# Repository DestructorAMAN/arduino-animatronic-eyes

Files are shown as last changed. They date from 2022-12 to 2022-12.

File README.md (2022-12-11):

# Arduino Animatronic Eyes
A computer science project I've build with a friend of mine. It's a pair of eyes which follow you when you walk past it.

The original code is (mostly) copied from [github.com/Nimrod-Galor/eye-animatronics](https://github.com/Nimrod-Galor/eye-animatronics)

We decided to put the eyes in a box behind a picture of Mark Zuckerberg. This way it looks like he's always watching you (as his eyes will follow you when you walk past him).

Front image
Back image
<details>
	<summary>Click to view the demo!</summary>
	Demo Video
</details>

# Material list
* The 3d printed files (see below)
* The laser cut files (see below) (if you only want the eyes and not the box, you can skip this)
* Arduino UNO
* 5x 9g servo
* ADNS 3080
* Jumper cables
* Optionally: IR LED's (+ matching resistors) for better visibility

# Tools list
* 3D printer => for the frame, eyeballs, eyelids and u-joints
* Laser cutter => for the box
* Soldering iron => to solder the jumper cables together

# 3D printed files
We've combined two thingiverse projects, [Doorman with eye holder & eyeball improvements](https://www.thingiverse.com/thing:3190675) and [The Doorman - Eyeball with ball joint](https://www.thingiverse.com/thing:3182820). The frame, eyeball and u-joint are from the first project. The eyelid is from the second one.

The eyes in the first design have a better connection with the frame (u-joint vs ball-joint). However, that design doesn't include the eyelid. The eyelid from the second design is compatible with the first design, so we just took it from there.

All files we used can be found in the `3d-files` directory. Remember that you need 2 eyeballs, 2 eyelids (you should scale them up a bit yourself) and 2 u-joints if you want to build this yourself.

# Laser cut files
We've laser cut the `box.svg` and `front_box.svg` from the `laser-files` directory. The dimensions of the box are the following: height: 47cm, width: 36cm.

The foam board we orded online with the dimensions of 34cm x 43cm and the file `zuck.webp` printed on it.

We hot glued the foam board to the back of the front panel, and hot glued the front panel to the sides. To mount the eyes we placed a small plate inside the box and glued everything together.

# Schematics
Schematics

# Capturing frames from the camera
You can use [github.com/RCmags/ADNS3080_frame_capture](https://github.com/RCmags/ADNS3080_frame_capture) to capture frames from the ADNS 3080. It requires you to first flash the `arduino_serial_output.ino` to the arduino and then run the python script. Make sure to set the correct serial port in the python script.

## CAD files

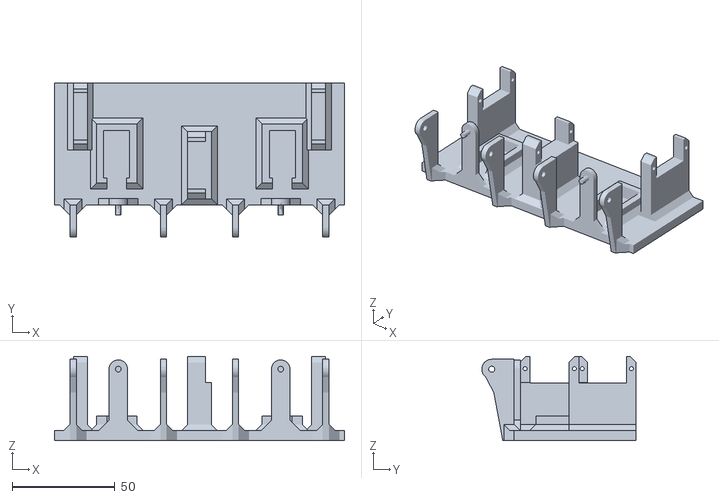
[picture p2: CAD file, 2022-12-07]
3d-files/frame.stl
140.9 x 75.0 x 41.0

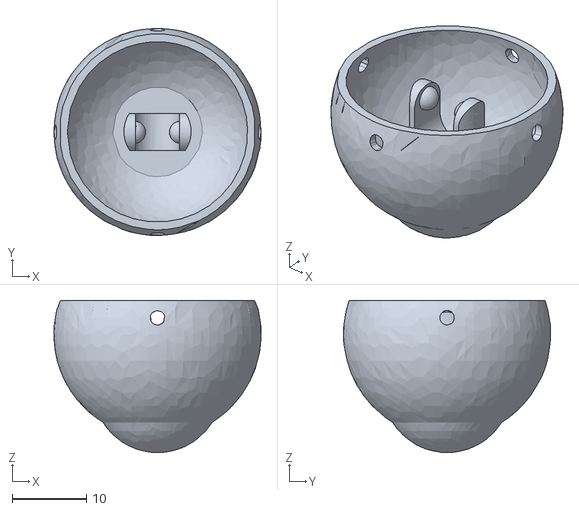
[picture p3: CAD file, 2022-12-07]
3d-files/eyeball.stl
27.9 x 28.0 x 20.6

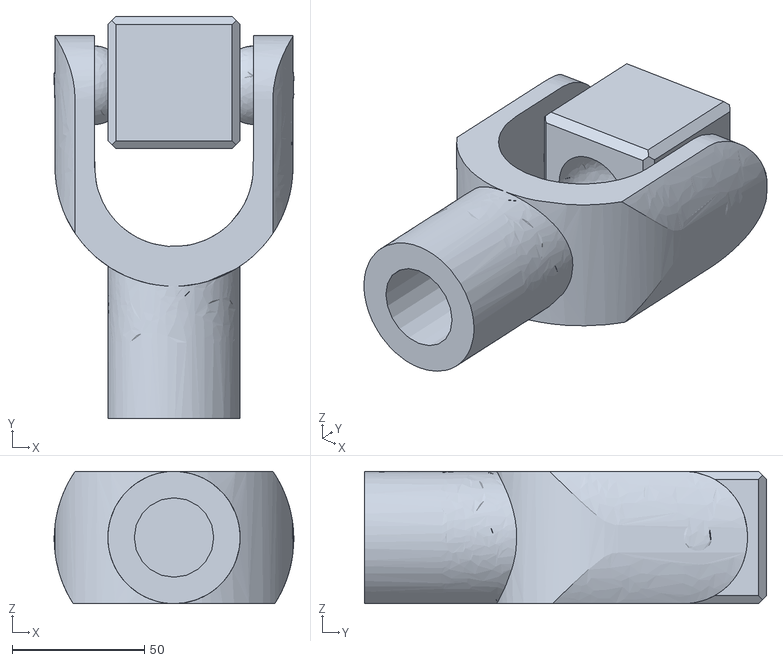
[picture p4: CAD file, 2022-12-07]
3d-files/ujoint.stl
90.6 x 152.0 x 50.0

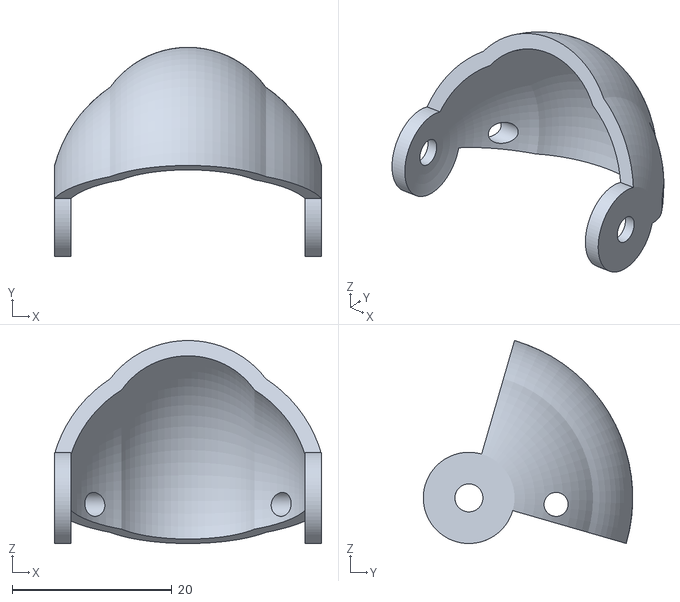
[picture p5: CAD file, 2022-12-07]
3d-files/eyelid.stl
33.4 x 26.2 x 25.4

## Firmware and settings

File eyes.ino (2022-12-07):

// import required libraries
#include <SPI.h>
#include <Servo.h>

// Debugging
#define DEBUG_QUALITY 0 // Print the quality of the camera if set to 1
#define DEBUG_XY 0 // Print the x/y coordinates if set to 1

// Left/right eye seen as the zuck himself (left eye in code = right eye if you stand in front of it)
Servo srvRx; // pin 2 - right eye swing
Servo srvRy; // pin 3 - right eye tilt
Servo srvLx; // pin 7 - left eye swing
Servo srvLy; // pin 6 - left eye tilt
Servo srvShut; // pin 5 - eyelids open/close

// Starting positions of the servo's
int posX = 90; // swing middle position
int posY = 90; // tilt middle position
int posS = 90; // shut start position

// Boundaries
// Without boundaries the servo's could move too far and break the eyes
// Or move too far and break the metal wire
short blinkMax = 105; // boundaries for eyelids
short blinkMin = 165; // boundaries for eyelids
short yMin = 39; // eye max up position
short yMax = 153; // eye max down position
short xMin = 60; // eye max right position
short xMax = 127; // eye max left position
short posYrev = 90; // reversed eye tilt position

// Other variables
short loopDelay = 10; // Slow down the loop with 10 ms

// Loop time for blinking
unsigned long blinkTime = 2000;

// No movement detected => rest = true => eyelids closed
unsigned long lastTrack = 0; // keeps track of when the last time movement is detected
bool rest = true; // keeps track of whether the eyes are in rest position (eyelids closed) or not

// Camera pins
#define PIN_MISO 12
#define PIN_MOSI 11
#define PIN_SCK 13
#define PIN_MOUSECAM_RESET 9
#define PIN_MOUSECAM_CS 10

// Amount of pixels on the camera
#define ADNS3080_PIXELS_X 30
#define ADNS3080_PIXELS_Y 30

// Camera Configuration
#define ADNS3080_PRODUCT_ID            0x00
#define ADNS3080_REVISION_ID           0x01
#define ADNS3080_MOTION                0x02
#define ADNS3080_DELTA_X               0x03
#define ADNS3080_DELTA_Y               0x04
#define ADNS3080_SQUAL                 0x05
#define ADNS3080_PIXEL_SUM             0x06
#define ADNS3080_MAXIMUM_PIXEL         0x07
#define ADNS3080_CONFIGURATION_BITS    0x0a
#define ADNS3080_EXTENDED_CONFIG       0x0b
#define ADNS3080_DATA_OUT_LOWER        0x0c
#define ADNS3080_DATA_OUT_UPPER        0x0d
#define ADNS3080_SHUTTER_LOWER         0x0e
#define ADNS3080_SHUTTER_UPPER         0x0f
#define ADNS3080_FRAME_PERIOD_LOWER    0x10
#define ADNS3080_FRAME_PERIOD_UPPER    0x11
#define ADNS3080_MOTION_CLEAR          0x12
#define ADNS3080_FRAME_CAPTURE         0x13
#define ADNS3080_SROM_ENABLE           0x14
#define ADNS3080_FRAME_PERIOD_MAX_BOUND_LOWER      0x19
#define ADNS3080_FRAME_PERIOD_MAX_BOUND_UPPER      0x1a
#define ADNS3080_FRAME_PERIOD_MIN_BOUND_LOWER      0x1b
#define ADNS3080_FRAME_PERIOD_MIN_BOUND_UPPER      0x1c
#define ADNS3080_SHUTTER_MAX_BOUND_LOWER           0x1e
#define ADNS3080_SHUTTER_MAX_BOUND_UPPER           0x1e
#define ADNS3080_SROM_ID               0x1f
#define ADNS3080_OBSERVATION           0x3d
#define ADNS3080_INVERSE_PRODUCT_ID    0x3f
#define ADNS3080_PIXEL_BURST           0x40
#define ADNS3080_MOTION_BURST          0x50
#define ADNS3080_SROM_LOAD             0x60
#define ADNS3080_PRODUCT_ID_VAL        23

// Reset the camera
void mousecam_reset()
{
  digitalWrite(PIN_MOUSECAM_RESET, HIGH);
  delay(1); // reset pulse >10us
  digitalWrite(PIN_MOUSECAM_RESET, LOW);
  delay(35); // 35ms from reset to functional
}

// Initialize/setup the camera
int mousecam_init()
{
  pinMode(PIN_MOUSECAM_RESET, OUTPUT);
  pinMode(PIN_MOUSECAM_CS, OUTPUT);
  digitalWrite(PIN_MOUSECAM_CS, HIGH);

  // Reset the camera
  mousecam_reset();

  // Make sure the camera is correctly connected by fetching the PID
  digitalWrite(PIN_MOUSECAM_CS, LOW);
  SPI.transfer(ADNS3080_PRODUCT_ID);
  delayMicroseconds(75);
  int pid = SPI.transfer(0xff);
  digitalWrite(PIN_MOUSECAM_CS, HIGH);
  delayMicroseconds(1);

  // Make sure the product id matches
  if (pid != ADNS3080_PRODUCT_ID_VAL) {
    Serial.println("PID Changed:");
    Serial.println(pid);
    return -1;
  }

  // Turn on sensitive mode
  digitalWrite(PIN_MOUSECAM_CS, LOW);
  SPI.transfer(ADNS3080_CONFIGURATION_BITS | 0x80);
  SPI.transfer(0x19);
  digitalWrite(PIN_MOUSECAM_CS, HIGH);
  delayMicroseconds(50);

  return 0;
}

// Related to fetching data from the camera
struct MD
{
  byte motion;
  char dx, dy;
  byte squal;
  word shutter;
  byte max_pix;
};

void mousecam_read_motion(struct MD *p)
{
  digitalWrite(PIN_MOUSECAM_CS, LOW);
  SPI.transfer(ADNS3080_MOTION_BURST);
  delayMicroseconds(75);
  p->motion = SPI.transfer(0xff);
  p->dx = SPI.transfer(0xff);
  p->dy = SPI.transfer(0xff);
  p->squal = SPI.transfer(0xff);
  p->shutter = SPI.transfer(0xff) << 8;
  p->shutter |= SPI.transfer(0xff);
  p->max_pix = SPI.transfer(0xff);
  digitalWrite(PIN_MOUSECAM_CS, HIGH);
  delayMicroseconds(5);
}

void setup()
{
  // Start serial connection on 57600
  Serial.begin(57600);

  // Set camera pins as input/output
  pinMode(PIN_MISO, INPUT);
  pinMode(PIN_MOSI, OUTPUT);
  pinMode(PIN_SCK, OUTPUT);

  // Configure serial connection with camera
  SPI.begin();
  SPI.setClockDivider(SPI_CLOCK_DIV32);
  SPI.setDataMode(SPI_MODE3);
  SPI.setBitOrder(MSBFIRST);

  // Make sure the camera is setup correctly
  if (mousecam_init() == -1)
  {
    Serial.println("Mouse cam failed to init");
    while (1);
  }

  // Set pins for servo's
  srvRx.attach(2);
  srvRy.attach(3);
  srvLx.attach(7);
  srvLy.attach(6);
  srvShut.attach(5);

  // Set servo's to start position
  srvRx.write(posX);
  srvLx.write(posX);
  srvRy.write(posY);
  srvLy.write(posY);
  srvShut.write(blinkMax);
}

void loop()
{
  // Slow down the loop
  delay(loopDelay);

  // Blinking mechanism
  if (!rest) {
    blinkTime = blinkTime - loopDelay;

    // When "blinkTime" is between 500 and 100 the eyelids will close and open
    if (blinkTime <= 100) { // Open eyelids
      srvShut.write(blinkMin);
      blinkTime = random(2, 12) * 500;
    } else if (blinkTime <= 500) { // Close eyelids
      srvShut.write(blinkMax);
    }
  }

  // Fetch the movement from the camera
  MD md;
  mousecam_read_motion(&md);

  // Quality debugging
  if (DEBUG_QUALITY != 0) {
    Serial.println(md.squal);
  }

  // If movement in x direction is detected
  if ((int)md.dx != 0) {

    // Make sure eyes are open when movement is detected (not in rest)
    if (rest) {
      srvShut.write(blinkMin);
      rest = false;
    }

    // Calculate new servo position
    posX -= (int)md.dx;
    if (posX > xMax) {
      posX = xMax;
    } else if (posX < xMin) {
      posX = xMin;
    }

    // Set eyes to new x position (swing)
    srvRx.write(180 - posX);
    srvLx.write(180 - posX);

    // Print x coordinate
    if (DEBUG_XY != 0) {
      Serial.print("X: ");
      Serial.println(posX);
    }

    // Update when last movement is detected
    lastTrack = millis();
  }

  // If movement in y direction is detected
  if ((int)md.dy != 0) {

    // Make sure eyes are open when movement is detected (not in rest)
    if (rest) {
      srvShut.write(blinkMin);
      rest = false;
    }

    // Calculate new servo position
    posY -= (int)md.dy;
    if (posY > yMax) {
      posY = yMax;
    } else if (posY < yMin) {
      posY = yMin;
    }

    // Set eyes to new y position (tilt)
    // Calculate reversed position (the left servo is rotated 180 degrees)
    posYrev = map(posY, yMin, yMax, yMax, yMin);
    srvRy.write(posY);
    srvLy.write(posYrev);

    // Print y coordinate
    if (DEBUG_XY != 0) {
      Serial.print("Y: ");
      Serial.println(posY);
    }

    // Update when last movement is detected
    lastTrack = millis();
  }

  // When no movement detected for 3 seconds, go to "rest" position (eyelids closed)
  if (millis() - lastTrack >= 3000) {
    rest = true;
    posX = 90; // swing
    posY = 90; // tilt
    posS = 90; // shut

    srvRx.write(posX);
    srvRy.write(posY);
    srvLx.write(posX);
    srvLy.write(posY);
    srvShut.write(blinkMax);
  }
}

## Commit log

2022-12-07 3d printed files
    [eyeball.stl, eyelid.stl, frame.stl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]
2022-12-08 Added laser cut box details
